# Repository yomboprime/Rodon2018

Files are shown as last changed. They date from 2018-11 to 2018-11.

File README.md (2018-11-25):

# Rodon2018
Open source wheeled robot.

This project will hold schematics, designs and code for a complete robot.

The robot electronics consist of an SBC (Raspberry-like board) and a Arduino/ESP/STM32-like board.

The main goal of the project is to create software for a wheeled robot suited for a diversity of common controller boards and hardware, i.e. Raspberry-like boards, microcontroller boards, and "Arduino modules". The particular hardware used in the project may differ from yours.

The libre tools used are: Kicad for the electronics, Freecad and Blender for the 3D designs, Inkscape for 2D artwork, and your favourite manner of editing code.

## Documentation

Please read the [project documentation](doc/1_DocumentationMain.md)

## Project phases history

- ✔️ Design MicrocontrollerBoard: Kicad design for the microcontroller board (Atmega1284P-PU)
- ➡️ Ordering and waiting for PCB arrival.
- Test MicrocontrollerBoard with motors.
- Do code a basic software & firmware.
- Keep growing functionality

## Acknowledgements

The small Lidar sensor code is based on the Adafruit VL53L0X Library, which is also MIT Licensed:

### Adafruit VL53L0X Library 

This is a library for the Adafruit VL53L0X time-of-flight breakout:
  * https://www.adafruit.com/products/3317
 
Check out the links above for our tutorials and wiring diagrams. This chip uses I2C to communicate

Adafruit invests time and resources providing this open source code, please support Adafruit and open-source hardware by purchasing products from Adafruit!

Written by Limor Fried/Ladyada for Adafruit Industries.
MIT license, all text above must be included in any redistribution

## License

MIT Licensed, see LICENSE file.

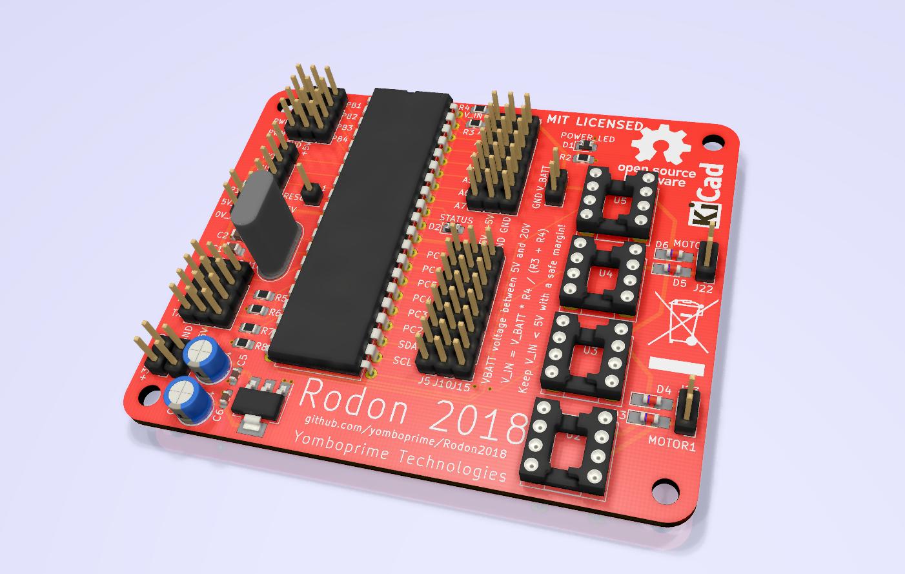
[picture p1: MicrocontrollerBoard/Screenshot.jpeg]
MicrocontrollerBoard


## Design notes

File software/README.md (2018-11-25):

# Software for Rodon2018 robot

- **Neocortex** is the Node.js software that runs on [CPUBoard](../doc/3_CPUBoard.md)
- **Medula_A** is the Arduino software that runs on [MicrocontrollerBoard](../doc/2_MicrocontrollerBoard.md) number 1.
- **Medula_B** is the Arduino software that runs on [MicrocontrollerBoard](../doc/2_MicrocontrollerBoard.md) number 2.

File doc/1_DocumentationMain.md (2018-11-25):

# Rodon2018 Documentation

## Components

The following sections define the different components of the robot.

- Electronics
- Sensors
- Actuators
- Power supply

### Electronics

The robot electronics consist of an SBC (Raspberry-like board) and a Arduino/ESP/STM32-like board. The particular hardware used in this project may differ from yours.

The first one has high level functions, while the second one controls hardware in real time. I will name them this way:

- CPUBoard: A GNU/Linux board (i.e., an SBC) You can use any Raspberry-like board for this.
- MicrocontrollerBoard: a microcontroller one. Any Arduino/ESPxx/STM board will be fine.

The CPUBoard code is cross-platform since it is Node.js based, and the Arduino code should be straightforward to run or port to other microcontrollers.

The CPUBoard will communicate with (and control the)  MicrocontrollerBoard through a serial port.

#### CPUBoard

This board will process high level functions and serve a web based interface.

The CPUBoard should have WiFi, and USB 2.0 support (to use a USB webcam, or alternatively, some other camera supported in Video4Linux). It should also have audio mic/output connectors, but it doesn't need video output. One UART is also needed. The UART can be a USB dongle one. If the UART is integrated, make sure it is the same voltage as the MicrocontrollerBoard one (3.3V or 5V) If it isn't, you should use voltage dividers, see the MicrocontrollerBoard section. 

See [NanoPi-Duo 2 board](3_CPUBoard.md) for more info about the SBC used in the project and how to adapt your own one.

#### MicrocontrollerBoard

The MicrocontrollerBoard controls most of the hardware in real time: it does servos and motors PWM control, read wheel encoders and control other things.

Besides the MicrocontrollerBoard, you will also need an H-Bridge dual motor driver board suited to control the power of the two wheel motors (in voltage and wattage), and another two H-bridges to control the stepper motor of the turret (alternatively a stepper motor driver module can be used for this)

In the project, two [custom MicrocontrollerBoard with integrated dual H-Bridge](2_MicrocontrollerBoard.md) are used. Read the previous link for more info on the board and how to use a generic one.

### Sensors

- [Wheel encoders](4_Sensors.md#wheel-encoders)
- [Turret endstop switch](4_Sensors.md#turret-endstop-switch)
- [Camera](4_Sensors.md#camera)
- [Microphone](4_Sensors.md#microphone)
- [Big lidar sensor](4_Sensors.md#big-lidar-sensor)
- [Small lidar sensor](4_Sensors.md#small-lidar-sensor)

### Actuators

- [Robot platform and motors](5_Actuators.md#robot-platform-and-motors)
- [Camera turret with stepper motor](5_Actuators.md#turret)
- [Arm](5_Actuators.md#arm)
- [Speaker](5_Actuators.md#speaker-and-audio-amplifier)
- [LED light](5_Actuators.md#led-light)

### Power supply

- [LiPo battery](6_PowerSupply.md#lipo-battery)
- [Step-down buck voltage converter](6_PowerSupply.md#step-down-buck-voltage-converter)

## Components interconnections

The following diagram shows the interconnections between the different components or modules.

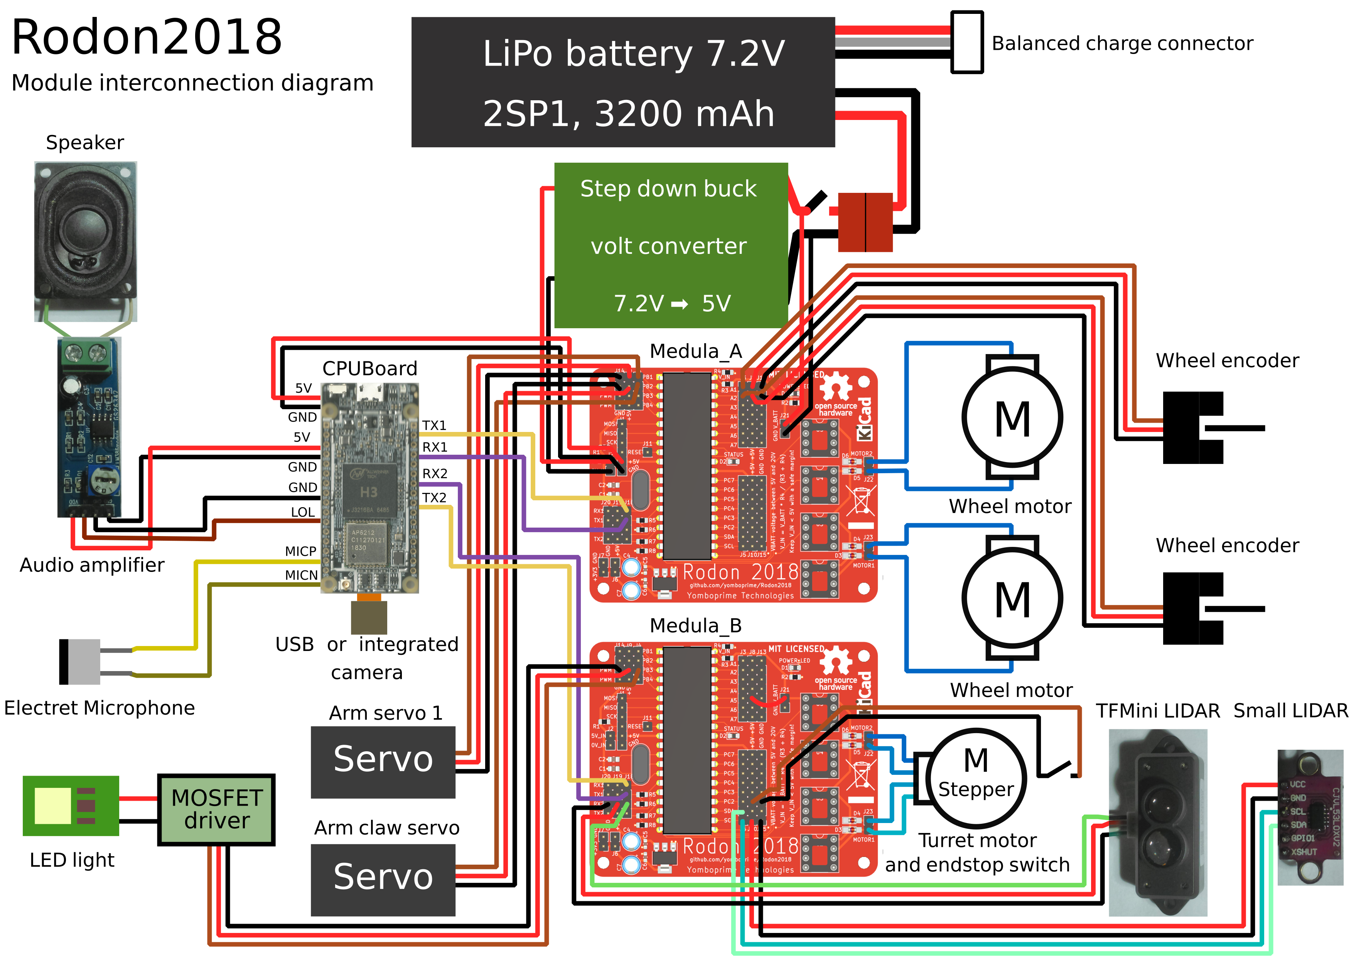
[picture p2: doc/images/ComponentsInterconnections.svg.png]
ComponentsInterconnections


**Legend:**

- LOL: Line Out Left, The left channel audio output pin.
- MICP, MICN: Positive and negative microphone pins.
- TX1, RX1: Transmit and receive pins of UART1
- TX2, RX2: Transmit and receive pins of UART2

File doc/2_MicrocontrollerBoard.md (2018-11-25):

# MicrocontrollerBoard

The MicrocontrollerBoard controls the motors, servos, reads the wheel encoders and activates other low bandwidth stuff. It responds to commands from the [CPUBoard](3_CPUBoard.md).

As with other components of the robot, you can use any Arduino/ESP/STM32 board you have around, the code is compatible. Just keep in mind:
 
- Check the voltage between the MicrocontrollerBoard and the CPUBoard. If both are 3.3V, everything is fine, but if one of them is 5V, you'll have to convert the voltages for the communication lines from 5V to 3V (unless the CPUBoard has also 5V UART, which is unlikely)
- You will need two resistors to form a voltage divider for the battery voltage sensing function.

Both of these points are implemented in the project's custom MicrocontrollerBoard.

As the software library used for the small LIDAR sensor is synchronous, I've decided to use two MicrocontrollerBoard's. This means I have 2x processing time. The reading of the two LIDARs and the turret motor control is done in the second MicrocontrollerBoard. If you use for example an ESP32, which has two cores, you can create two tasks and assign each one the `setup()` and `loop()` of each of the two Arduino sketches.

The software for the MicrocontrollerBoard is called Medula. Since there are two MicrocontrollerBoard's, the Arduino sketches are called **Medula_A** and **Medula_B**. Also, the CPUBoard needs two UARTs to communicate with them. 

**The code for this board is W.I.P.**

## Pins, peripherals, pinout assignment

Check the pinout assignment with your board and change the code accordingly.

The needed pins/peripherals on the MicrocontrollerBoard are:

- 4x PWM output pins for the wheel motors.
- 2x digital input pins for the wheel encoders.
- 4x output pins for the turret stepper motor.
- 1x digital input pin for the turret endstop switch.
- 1x analog input with two resistors forming a voltage divider, to sense the battery voltage.
- 1x UART for communications with the CPUBoard
- 1x UART to read the TFMini LIDAR.
- 1x I2C to read the small LIDAR sensor.
- A way for programming it, either ICSP or another UART via bootloader.

## Project board
 
The board used and designed for this project uses an Atmel ATMEGA1284P-PU microcontroller. It is designed with a mix of THT and SMD components I had laying around. Its features are:

- Supply voltage is 5V
- 16 MHz crystal is used.
- Dual Full H-Bridge implemented with four TC4422 (2A per motor)
- Separate motor battery voltage from 5V to 20V
- Exposes 22 pins with neighbour 5V and GND (7 of the pins are analog inputs, 2 have hardware PWM, 2x UART, 1x I2C)
- Voltage conversion resistors for 2xUART, and A0 (analog input 0, to sense battery voltage)
- Can be programmed via bootloader (UART) or ICSP (SPI)
- 3V3 voltage regulator to power other modules.
- Power indication LED
- Status (general purpose) LED on PB0

The Kicad design of this board is located [here](../MicrocontrollerBoard/kicad_project/).

Two of this boards are used, distributing the connected peripherals as follows:

### MicrocontrollerBoard: Medula_A

- The two H-bridges control the wheel motors.
- The two wheel encoders are connected to pins A1 and A2.
- 7.2V battery voltage is measured at V_IN (A0)
- UART1 (Serial) is connected to CPUBoard. UART2 is not used.
- 5V voltage from the step-down converter is connected to this board and distributed from here to CPUBoard, Medula_B and all other modules.

### MicrocontrollerBoard: Medula_B

- The two H-bridges control the turret stepper motor.
- The turret endstop switch is connected to PC2 pin.
- The TFMini LIDAR is connected to UART2 (Serial1) Only the TX pin from the LIDAR is used.
- The small LIDAR is connected via I2C (pins SCL and SDA)
- UART1 (Serial) is connected to CPUBoard.

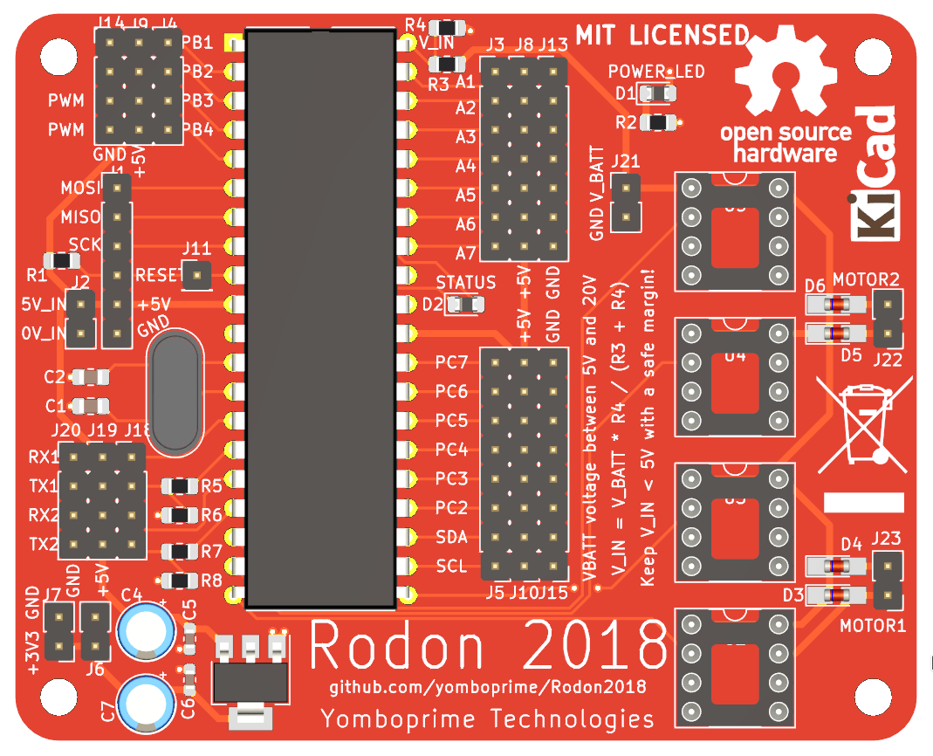
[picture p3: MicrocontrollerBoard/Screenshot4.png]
MicrocontrollerBoard


MicrocontrollerBoard

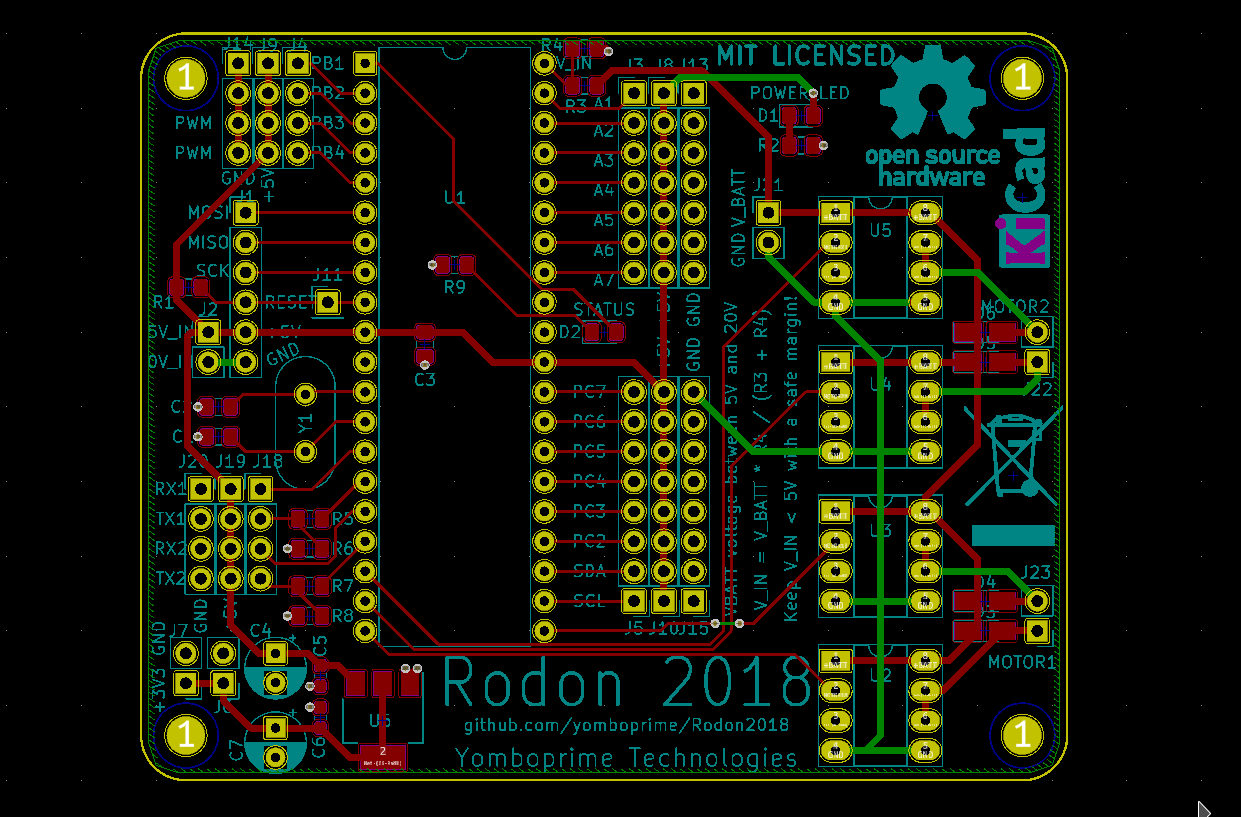
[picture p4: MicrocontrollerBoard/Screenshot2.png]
MicrocontrollerBoard2


### Voltage dividers

A voltage divider is used to convert a voltage to a lower one and is formed by two resistors, let's say Ra and Rb. These two resistors are connected in series. Ra is connected in one end to the higher voltage, the point between Ra and Rb is connected to the lower voltage output, and the other Rb end is connected to ground. Then, `Vlow = Vhigh * Rb / ( Ra + Rb)`.

#### UART voltage dividers

To allow the conversion of 5V to 3V3 on the communication pins that are outputs (TX) connected to the [CPUBoard](3_CPUBoard.md), consult the values for each resistor pair:

Output pin|Ra|Rb
----------|--|--
TX1|R5 = 1K|R6 = 2K
TX2|R7 = 1K|R8 = 2K
MISO|R10 = 1K|R11 = 2K

Note that only output pins need conversion. Driving a 5V input from a 3V3 output is safe.

Also, TX2 voltage divider may not be needed.

#### Battery sense voltage divider

The battery voltage, which can be greater than 5V, is read through an analog input pin which can tolerate a maximum of 5V. To do this, a voltage divider is used with V_BATT as input and V_IN as output, using R3 and R4, with values near to 1K.

To calculate the values for R3 and R4:

`V_IN = V_BATT * R4 / (R3 + R4)`

If we want to be able to measure 2S and 3S batteries, say a 15V maximum is a safe top level. Then,

`5V = 15V * R4 / (R3 + R4)`

`1/3 = R4 / (R3 + R4)`

`(R3 + R4) / 3 = R4`

`((R3 / R4) + 1) / 3 = 1`

`R3 / R4 = 2`

`R3 = 2 * R4`

If we choose R4 = 1K, then R3 must be 2K. We choose the standard value 2K2, and then calculate again the max voltage we'll get at V_IN:

`V_IN = 15V * 1K / (1K + 2K2)`

`V_IN = 4.6875V`

So we can get again the theoretical maximum measurable voltage based on these resistors values:

`V_BATT = 15V * 5v / 4.6875V = 16V`

Which is exactly 16V.

So we can use the 10 bit ADC from the ATMEGA microcontroller to measure in steps of 16V/1024, or 15.625mV.

To calibrate with the real resistors values, the V_BATT, R3_RESISTOR and R4_RESISTOR values can be changed in the code. (W.I.P.)

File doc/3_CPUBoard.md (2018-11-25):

# CPUBoard

CPUBoard is the board used as the main robot CPU. As with other components of the robot, you can use any Raspberry-like board you've got around, the code is compatible. The robot server software that runs in CPUBoard is called Neocortex and is written in js. It runs in Node.js, which is a multi-platform runtime for the js language. When using your CPUBoard just keep in mind:
 
- Check the voltage between the CPUBoard and the MicrocontrollerBoard. If both are 3.3V, everything is fine, but if one of them is 5V, you'll have to convert the voltages for the communication lines from 5V to 3V. This is done in the [custom MicrocontrollerBoard](2_MicrocontrollerBoard.md)

## Features of CPUBoard

The needed features on the CPUBoard are:

- Compatible GNU/Linux operating system.
- WiFi
- 2x UART to communicate with the two MicrocontrollerBoards (or only one if you use only one MicrocontrollerBoard, like an ESP32)
- A video camera compatible with Video4Linux.
- Analogue audio output (mono, or stereo if you want)
- Analogue microphone input.

## Project board

The CPUBoard used in this project is a [FriendlyArm NanoPi-Duo 2 SBC](http://wiki.friendlyarm.com/wiki/index.php/NanoPi_Duo2), which is a SBC in very small factor with only pin headers broken out, a OV5640 video camera connector, microUSB and microSD.

The pins corresponding to the SPI port are used here as the alternate function (a second UART) So SCK corresponds to RX2, and CS to TX2.

## The software: Neocortex

**The code for this board is W.I.P. and is not completed yet.**

### Prerequisites instalation

- Node.js is required. Read [Node.js docs](https://nodejs.org/) on how to install for your OS.

### Instalation

W.I.P

- Clone [Rodon2018 repository](https://github.com/yomboprime/Rodon2018.git) into the CPUBoard file system (`Rodon2018/` from now on)
- Install Node.js library dependecies by issuing these commands:
  - `cd Rodon2018/software/Neocortex/`
  - `npm install`

### WiFi configuration

Please refer to your OS documentation on how to set up a WiFi network. You can either:

- Use a common WiFi network accessible by CPUBoard and the client system/s, or
- Configure CPUBoard to create an adhoc WiFi network, accessible by the client/s.

It is recommended to set a static IP so you won't have to find CPUBoard in the network each time.

### Running Neocortex in CPUBoard

#### Executing to test it

To simply do a run test of the software, do just:

- `cd Rodon2018/software/Neocortex/`
- `npm start`

Press (ctrl-c) to exit at any time.

#### Run at system startup

To execute Neocortex at system startup automatically, usually adding these lines at the end of the `/etc.rc.local` file will suffice:

- `cd /absolute_path_to_Rodon2018/software/Neocortex/`
- `npm start || exit 1`
- `exit 0`

In this configuration, the system will have to be shutdown by the client web interface or from a ssh terminal.

#### Running the web interface in a client

Any browser-capable device can be a client. Just:

- Connect to the same network the CPUBoard is connected to.
- Navigate with a modern browser to `http://<ip>:<port>/public`

Where:

- `<ip>` is the static IP address of CPUBoard in the network.
- `<port>` is the application TCP port as defined in the Neocortex configuration file (TODO link file doc).

Example: `http://192.168.1.189:8090/public`

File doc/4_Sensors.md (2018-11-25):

# Sensors

## Wheel encoders

Simple on/off encoders are used, to provide speed/relative movement between readings for each wheel. You can set the number of marks per revolution in the code. The left and right wheel encoders are attached to two pins on the [MicrocontrollerBoard](2_MicrocontrollerBoard.md)

## Turret endstop switch

A common switch of any type can be used. It must be normally-open type.

## Camera

A USB webcam or integrated camera which can support Video4Linux can be used, attached to the [CPUBoard](3_CPUBoard.md) First I was going to use this cheap VGA USB camera, but then upgraded to Nanopi-Duo 2 for the CPUBoard which has integrated 1080p@30FPS camera sensor.

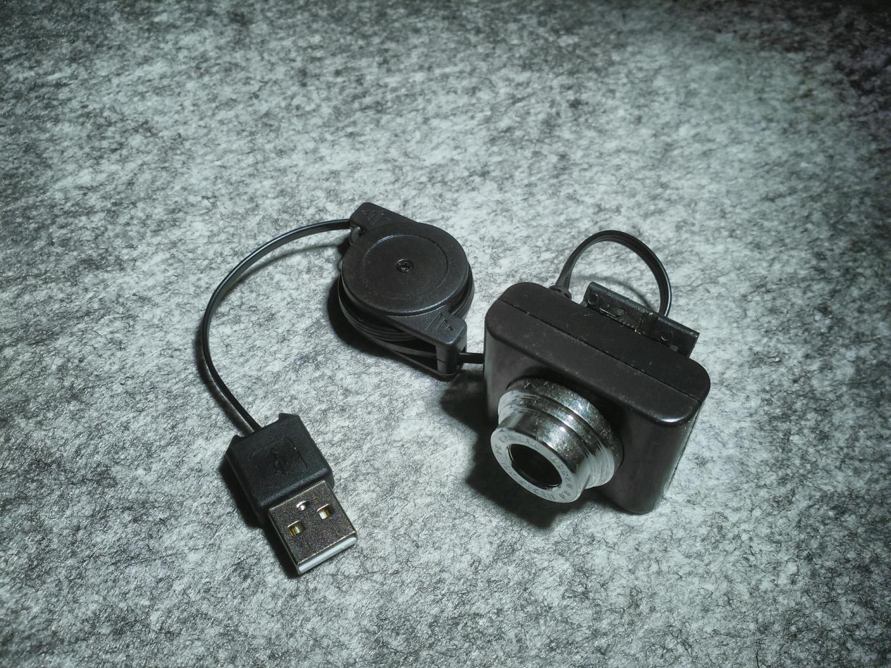
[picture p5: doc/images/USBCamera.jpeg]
USBCamera


## Microphone

Any microphone that can be connected to the MIC input of your [CPUBoard](3_CPUBoard.md) will serve. A simple and inexpensive electret microphone is used in the project, connected directly to the MICP and MICN (positive and negative) inputs in the CPUBoard. Keep in mind the polarity, the negative pin in the electret is the one connected to the chassis with pcb tracks in the back, as shown in the following photo.

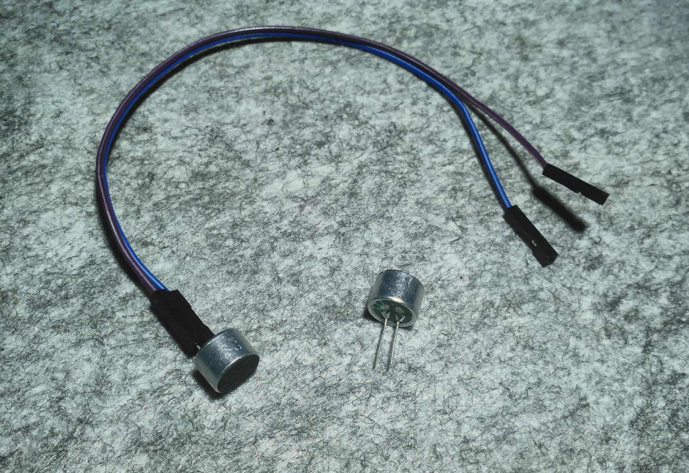
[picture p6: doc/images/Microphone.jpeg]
Microphone


## Big LIDAR Sensor

The TF-Mini LIDAR sensor is a 30 to 2000 cm range LASER distance sensor with 1 cm precision and UART interface. Only TX line (reading from the sensor) is needed, attached to the [MicrocontrollerBoard](2_MicrocontrollerBoard.md) Medula_B

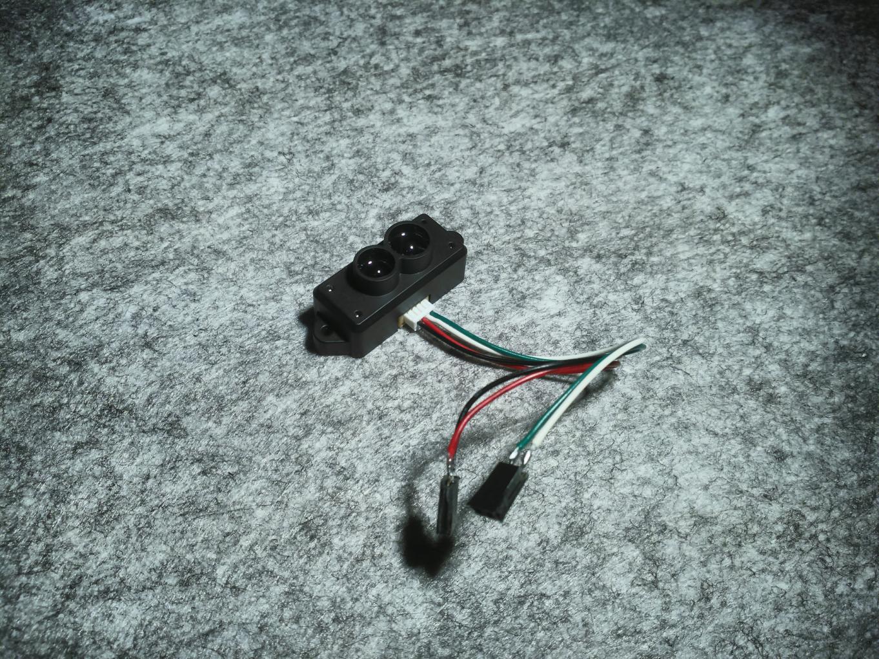
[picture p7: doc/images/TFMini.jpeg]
TFMini


## Small LIDAR Sensor

The V53L0X LIDAR sensor is used in conjunction with the TF-Mini to increase its short range capabilities. This is a 5 to 120 cm range LIDAR sensor with 1 mm precision. I has I2C interface, connected to the [MicrocontrollerBoard](2_MicrocontrollerBoard.md) Medula_B

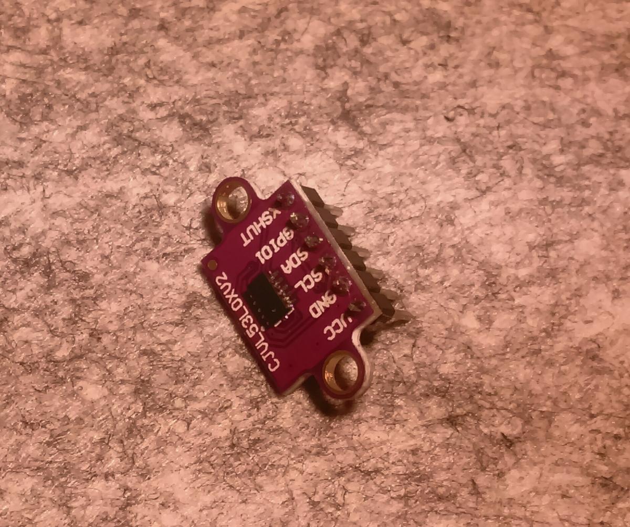
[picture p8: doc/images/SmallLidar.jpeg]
SmallLidar


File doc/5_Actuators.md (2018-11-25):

# Actuators

## Robot platform and motors

Any robot base with motors and wheel encoders can be used. In the project, an old robot platform is used (which parts were included in magazines from the old company EagleMoss Publications Ltd.) Wheel encoders obtained from an old matrix printer were added (they have 50 marks per revolution). Also was added to the platform a stronger free rotation third wheel. A black electronics box was also installed. 3D printed parts will be added for the turret and arm.

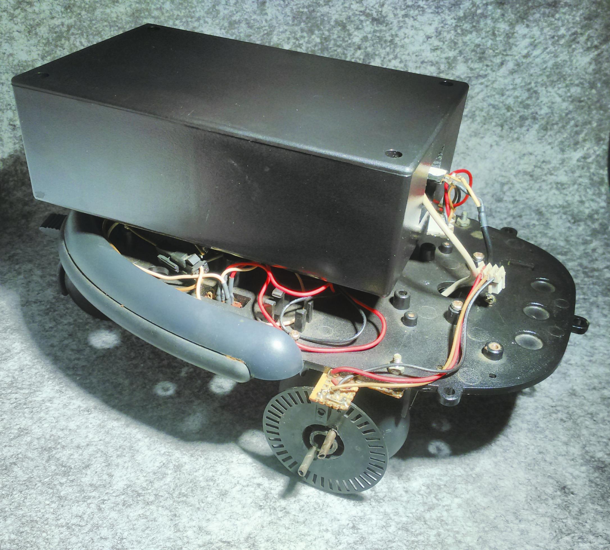
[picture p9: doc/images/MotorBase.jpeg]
MotorBase


W.I.P.

## Turret

A custom 3D printed turret which holds the [CPUBoard](3_CPUBoard.md) and its integrated camera (and also the two LIDARs) will be mounted. It will rotate with a small 5V stepper motor. The turret will only rotate horizontally.

W.I.P.

## Arm

A custom 3D printed arm which can lift soda cans will be mounted. It will have a medium size servo for the arm and a miniservo for the clamp.

W.I.P.

## Speaker and audio amplifier

A speaker with an audio amplifier module at 5V will be used to reproduce sounds from the [CPUBoard](3_CPUBoard.md). Just mono sound is OK.

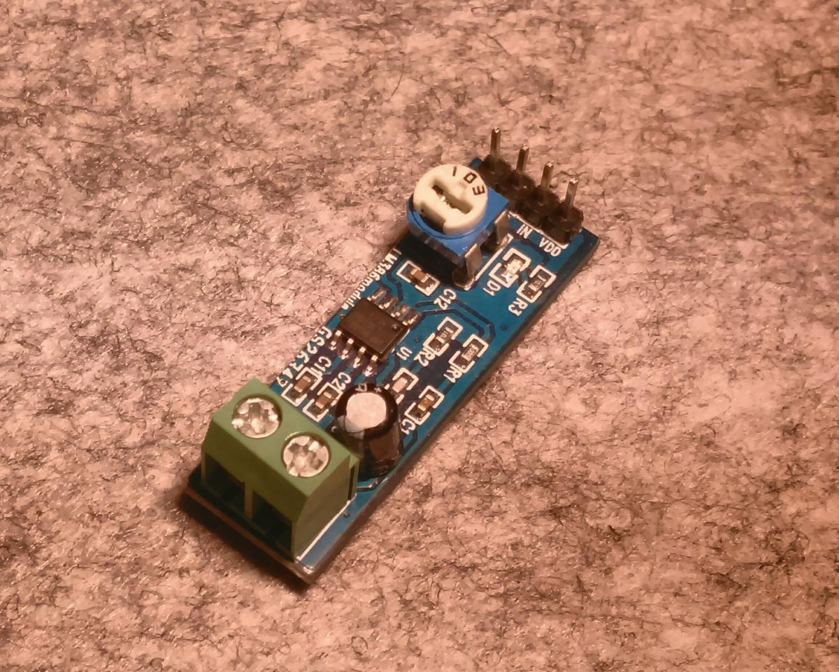
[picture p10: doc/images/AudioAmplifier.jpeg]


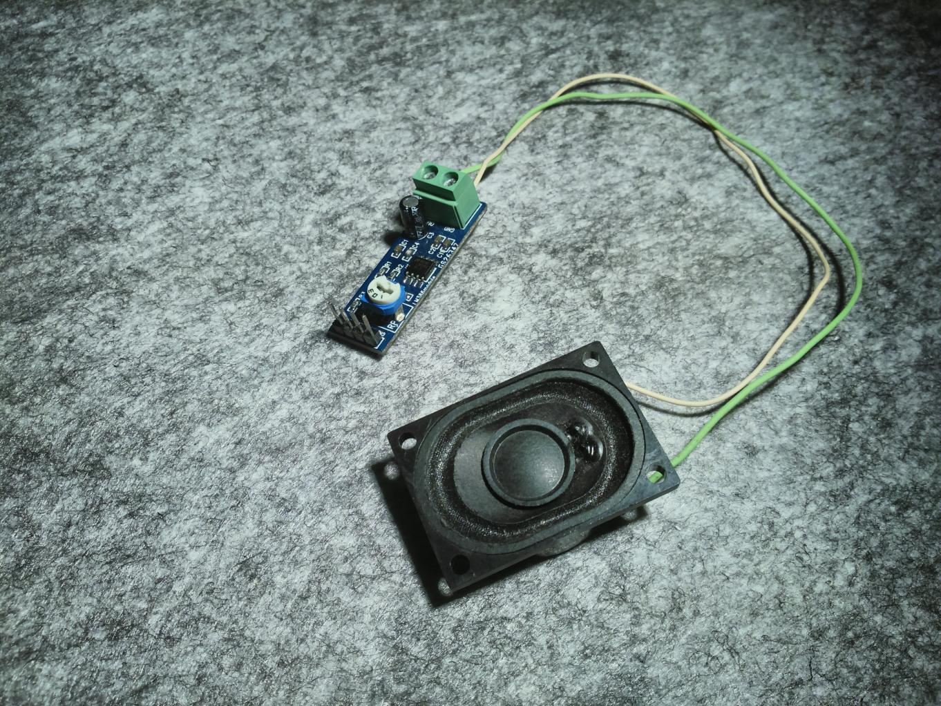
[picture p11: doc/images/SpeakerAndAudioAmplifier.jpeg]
SpeakerAndAudioAmplifier


## LED light

A LED light is used for illumination. It can be any power LED with its current limiting resistor. It is controlled with a MOSFET driver at 5V.

W.I.P.

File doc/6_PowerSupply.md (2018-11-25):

# Power supply

The robot can be powered with Li-Po or Li-ion batteries. Best is two or three cells (2S/3S batteries)

The batteries will have to be charged either by extracting them or providing a charging circuit.

In the project, a *deans* connector is used to unconnect from the robot and connect to the charger externally. During development, a LiPo battery tester is used, connected to the balanced charge connector.

## LiPo battery

In the project, a 2S Li-Po battery with 3300 mAh charge is used. During periods of non use it will be extracted and kept safe.

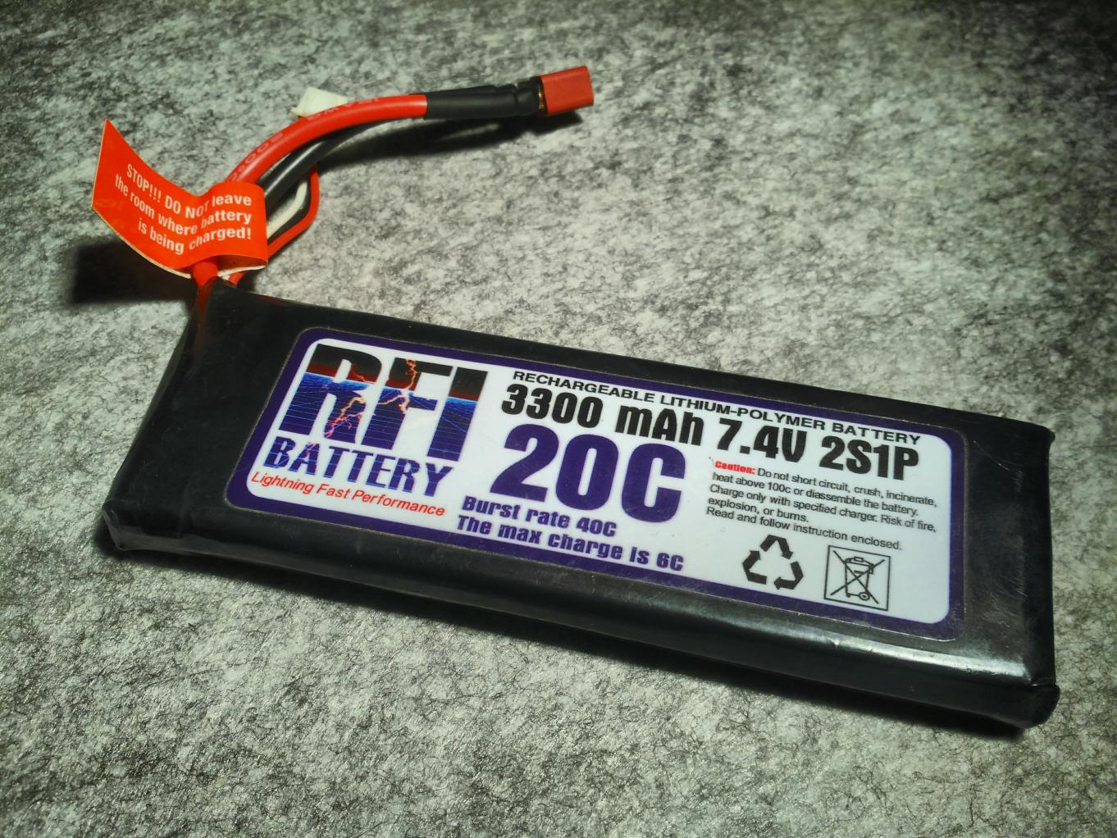
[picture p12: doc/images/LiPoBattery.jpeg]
LiPoBattery


## Step-down buck voltage converter

To provide 5V for the [CPUBoard](3_CPUBoard.md) and the [MicrocontrollerBoard](2_MicrocontrollerBoard.md), a step-down buck converter will be used. The battery voltage will be applied to its input, and it will supply 5V @ 4A to both boards. These step down modules are adjusted without load before operation, with its potentiometers.

You can decide in your robot at what voltage you want to run the servos and the motors. Servos can be used with 2S batteries (up to about 7.4V), but 3S (11V or more) is too high. Check also your motors maximum voltage.

In the project, the 2S battery is connected to the battery connector in the [MicrocontrollerBoard](2_MicrocontrollerBoard.md), so the battery powers the motors directly. On the other hand, the servos and the turret motor are powered with 5V.

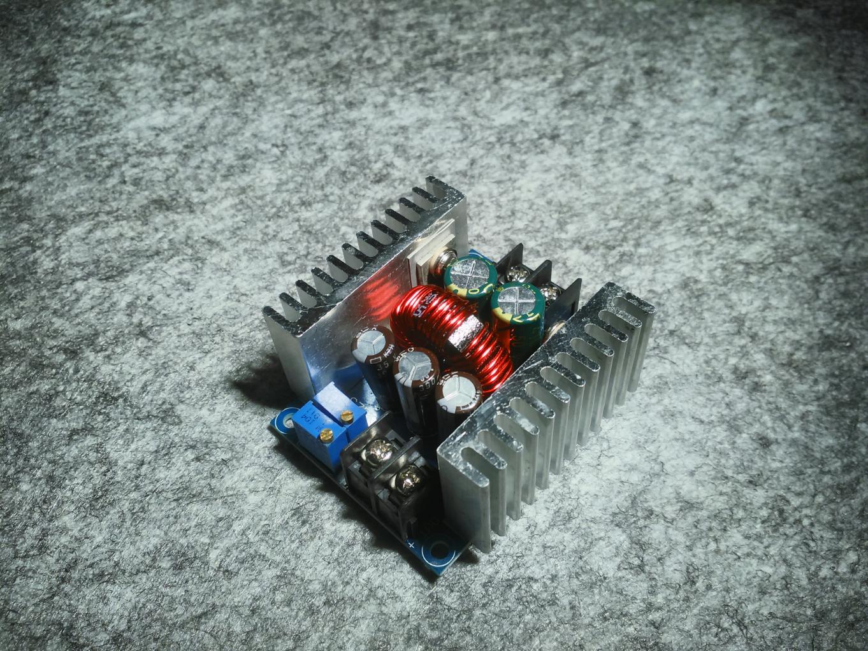
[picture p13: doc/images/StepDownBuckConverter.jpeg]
StepDownBuckConverter


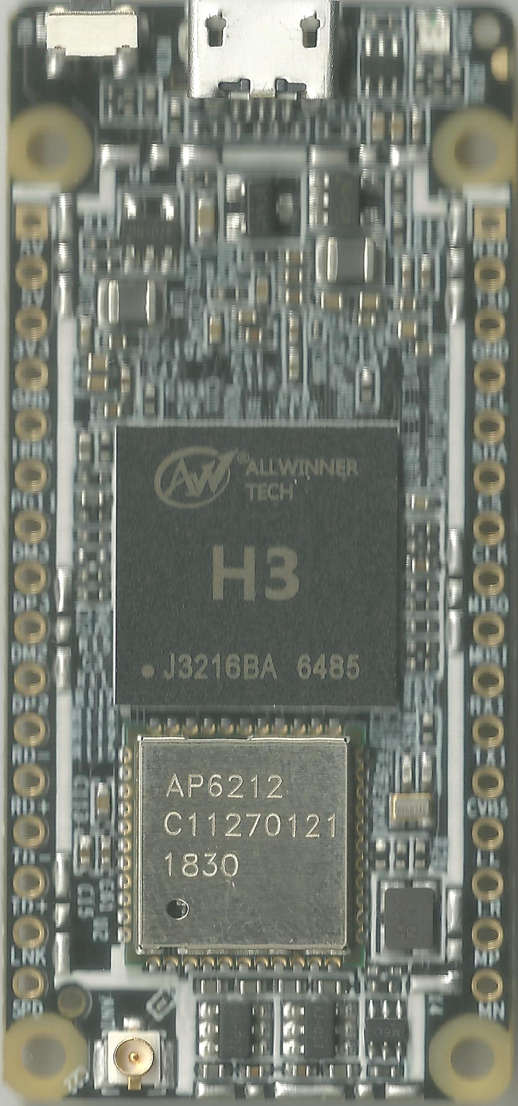
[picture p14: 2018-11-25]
doc/images/Nanopi_Duo_2.jpeg

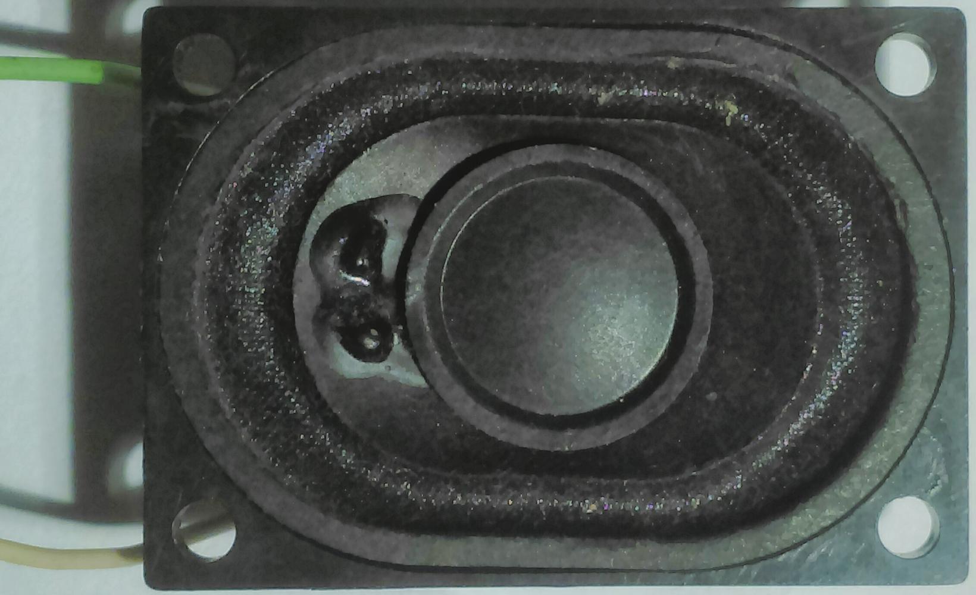
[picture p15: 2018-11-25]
doc/images/Speaker_Plant.jpeg

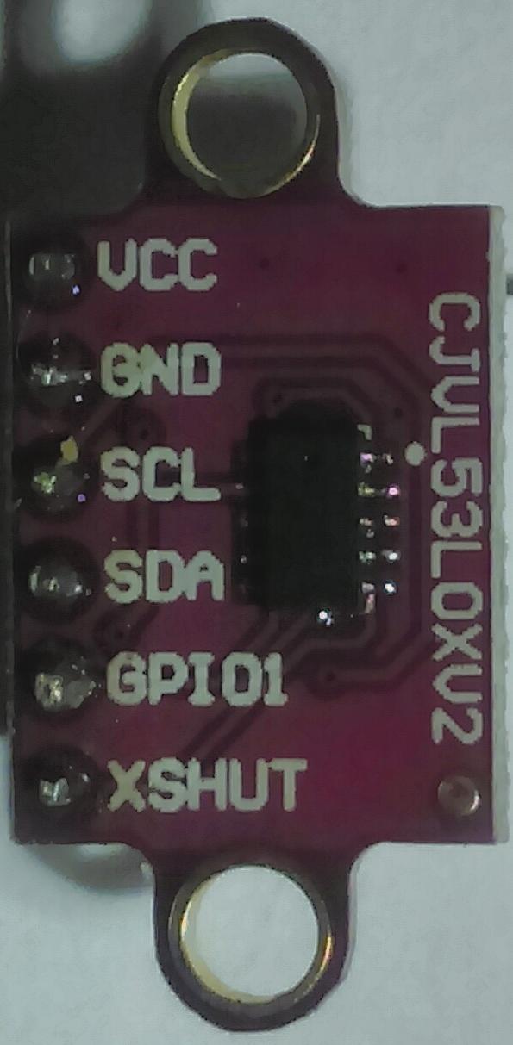
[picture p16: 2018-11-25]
doc/images/SmallLidar_Plant.jpeg

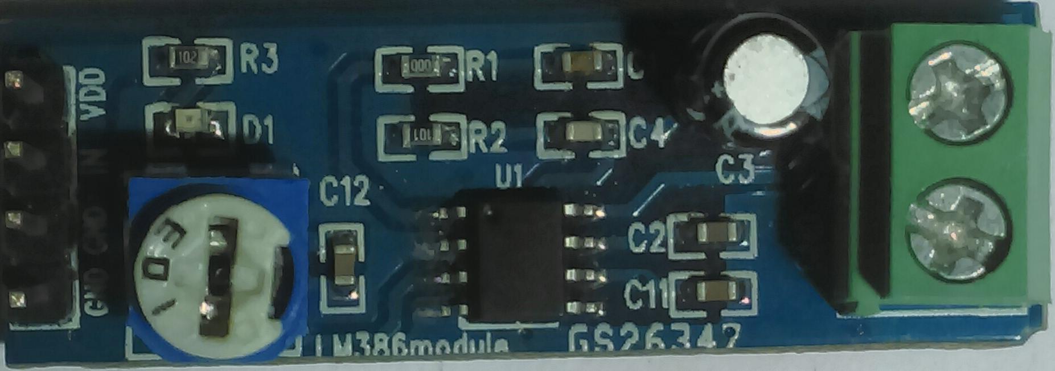
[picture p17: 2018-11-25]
doc/images/AudioAmplifier_Plant.jpeg

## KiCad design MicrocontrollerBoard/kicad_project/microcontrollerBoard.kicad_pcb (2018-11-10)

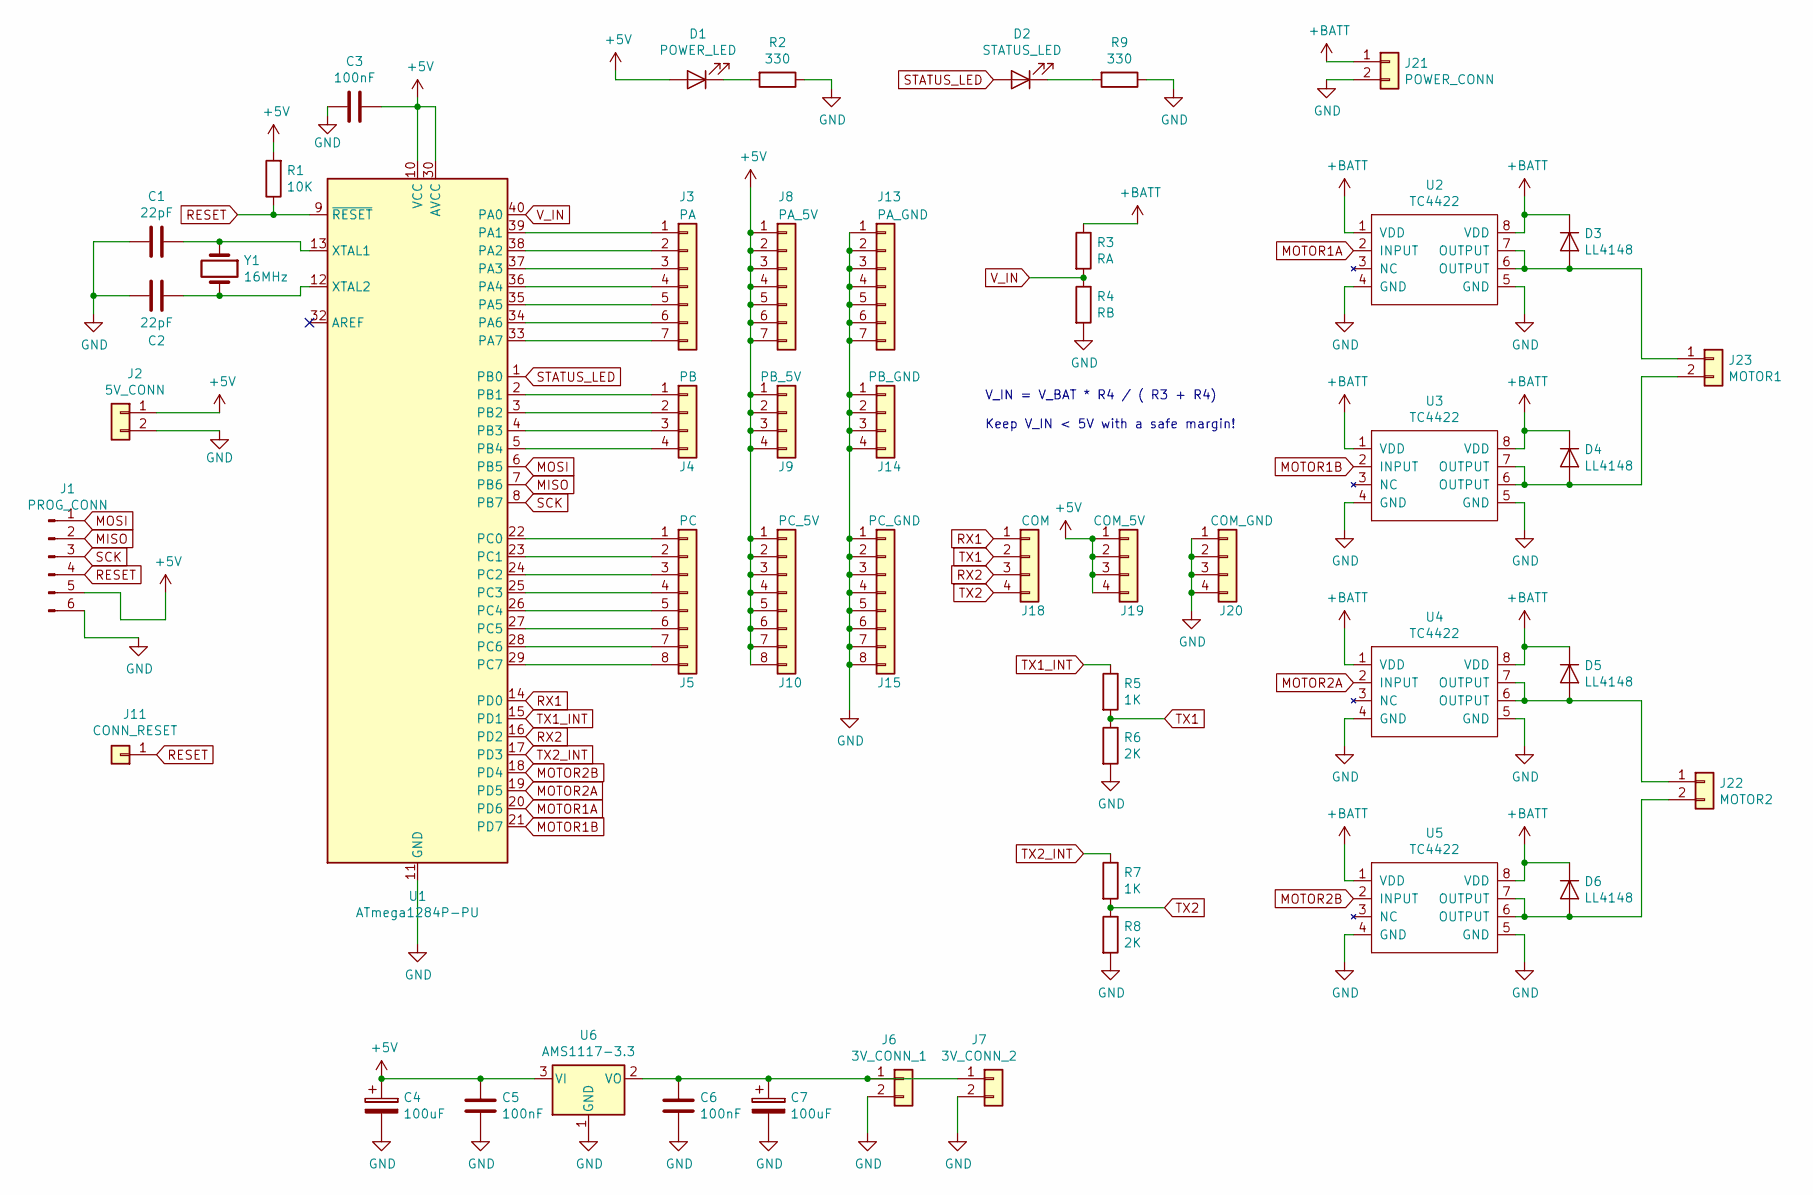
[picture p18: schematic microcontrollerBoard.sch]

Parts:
C1, C2: 22pF; C_0805_2012Metric_Pad1.15x1.40mm_HandSolder
C3: 100nF; C_0805_2012Metric_Pad1.15x1.40mm_HandSolder
C4, C7: 100uF; CP_Radial_D5.0mm_P2.50mm
C5, C6: 100nF; C_0603_1608Metric_Pad1.05x0.95mm_HandSolder
D1: POWER_LED; D_0805_2012Metric_Pad1.15x1.40mm_HandSolder
D2: STATUS_LED; D_0805_2012Metric_Pad1.15x1.40mm_HandSolder
D3, D4, D5, D6: LL4148; D_SOD-110
J1: PROG_CONN; PinHeader_1x06_P2.54mm_Vertical
J2: 5V_CONN; PinHeader_1x02_P2.54mm_Vertical
J3: PA; PinHeader_1x07_P2.54mm_Vertical
J4: PB; PinHeader_1x04_P2.54mm_Vertical
J5: PC; PinHeader_1x08_P2.54mm_Vertical
J6: 3V_CONN_1; PinHeader_1x02_P2.54mm_Vertical
J7: 3V_CONN_2; PinHeader_1x02_P2.54mm_Vertical
J8: PA_5V; PinHeader_1x07_P2.54mm_Vertical
J9: PB_5V; PinHeader_1x04_P2.54mm_Vertical
J10: PC_5V; PinHeader_1x08_P2.54mm_Vertical
J11: CONN_RESET; PinHeader_1x01_P2.54mm_Vertical
J13: PA_GND; PinHeader_1x07_P2.54mm_Vertical
J14: PB_GND; PinHeader_1x04_P2.54mm_Vertical
J15: PC_GND; PinHeader_1x08_P2.54mm_Vertical
J18: COM; PinHeader_1x04_P2.54mm_Vertical
J19: COM_5V; PinHeader_1x04_P2.54mm_Vertical
J20: COM_GND; PinHeader_1x04_P2.54mm_Vertical
J21: POWER_CONN; PinHeader_1x02_P2.54mm_Vertical
J22: MOTOR2; PinHeader_1x02_P2.54mm_Vertical
J23: MOTOR1; PinHeader_1x02_P2.54mm_Vertical
R1: 10K; R_0805_2012Metric_Pad1.15x1.40mm_HandSolder
R2, R9: 330; R_0805_2012Metric_Pad1.15x1.40mm_HandSolder
R3: RA; R_0805_2012Metric_Pad1.15x1.40mm_HandSolder
R4: RB; R_0805_2012Metric_Pad1.15x1.40mm_HandSolder
R5, R7: 1K; R_0805_2012Metric_Pad1.15x1.40mm_HandSolder
R6, R8: 2K; R_0805_2012Metric_Pad1.15x1.40mm_HandSolder
U1: ATmega1284P-PU; DIP-40_W15.24mm
U2, U3, U4, U5: TC4422; DIP-8_W7.62mm_Socket_LongPads
U6: AMS1117-3.3; SOT-223-3_TabPin2
Y1: 16MHz; Crystal_HC49-U_Vertical

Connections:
+5V: C3.1, C4.1, C5.1, D1.2 (A), J1.5, J2.1, J8.1, J8.2, J8.3, J8.4, J8.5, J8.6, J8.7, J9.1, J9.2, J9.3, J9.4, J10.1, J10.2, J10.3, J10.4, J10.5, J10.6, J10.7, J10.8, J19.1, J19.2, J19.3, J19.4, R1.2, U1.10 (VCC), U1.30 (AVCC), U6.3 (VI)
+BATT: D3.1 (K), D4.1 (K), D5.1 (K), D6.1 (K), J21.1, R3.1, U2.1 (VDD), U2.8 (VDD), U3.1 (VDD), U3.8 (VDD), U4.1 (VDD), U4.8 (VDD), U5.1 (VDD), U5.8 (VDD)
GND: C1.2, C2.2, C3.2, C4.2, C5.2, C6.2, C7.2, J1.6, J2.2, J6.2, J7.2, J13.1, J13.2, J13.3, J13.4, J13.5, J13.6, J13.7, J14.1, J14.2, J14.3, J14.4, J15.1, J15.2, J15.3, J15.4, J15.5, J15.6, J15.7, J15.8, J20.1, J20.2, J20.3, J20.4, J21.2, R2.1, R4.2, R6.2, R8.2, R9.1, U1.11 (GND), U1.31 (GND), U2.4 (GND), U2.5 (GND), U3.4 (GND), U3.5 (GND), U4.4 (GND), U4.5 (GND), U5.4 (GND), U5.5 (GND), U6.1 (GND)
MISO: J1.2, U1.7 (PB6)
MOSI: J1.1, U1.6 (PB5)
MOTOR1A: U1.20 (PD6), U2.2 (INPUT)
MOTOR1B: U1.21 (PD7), U3.2 (INPUT)
MOTOR2A: U1.19 (PD5), U4.2 (INPUT)
MOTOR2B: U1.18 (PD4), U5.2 (INPUT)
unnamed: C1.1, U1.13 (XTAL1), Y1.1
unnamed: C2.1, U1.12 (XTAL2), Y1.2
unnamed: C6.1, C7.1, J6.1, J7.1, U6.2 (VO)
unnamed: D1.1 (K), R2.2
unnamed: D2.1 (K), R9.2
unnamed: D3.2 (A), J23.1, U2.6 (OUTPUT), U2.7 (OUTPUT)
unnamed: D4.2 (A), J23.2, U3.6 (OUTPUT), U3.7 (OUTPUT)
unnamed: D5.2 (A), J22.1, U4.6 (OUTPUT), U4.7 (OUTPUT)
unnamed: D6.2 (A), J22.2, U5.6 (OUTPUT), U5.7 (OUTPUT)
unnamed: J3.1, U1.39 (PA1)
unnamed: J3.2, U1.38 (PA2)
unnamed: J3.3, U1.37 (PA3)
unnamed: J3.4, U1.36 (PA4)
unnamed: J3.5, U1.35 (PA5)
unnamed: J3.6, U1.34 (PA6)
unnamed: J3.7, U1.33 (PA7)
unnamed: J4.1, U1.2 (PB1)
unnamed: J4.2, U1.3 (PB2)
unnamed: J4.3, U1.4 (PB3)
unnamed: J4.4, U1.5 (PB4)
unnamed: J5.1, U1.22 (PC0)
unnamed: J5.2, U1.23 (PC1)
unnamed: J5.3, U1.24 (PC2)
unnamed: J5.4, U1.25 (PC3)
unnamed: J5.5, U1.26 (PC4)
unnamed: J5.6, U1.27 (PC5)
unnamed: J5.7, U1.28 (PC6)
unnamed: J5.8, U1.29 (PC7)
RESET: J1.4, J11.1, R1.1, U1.9 (~RESET)
RX1: J18.1, U1.14 (PD0)
RX2: J18.3, U1.16 (PD2)
SCK: J1.3, U1.8 (PB7)
STATUS_LED: D2.2 (A), U1.1 (PB0)
TX1: J18.2, R5.2, R6.1
TX1_INT: R5.1, U1.15 (PD1)
TX2: J18.4, R7.2, R8.1
TX2_INT: R7.1, U1.17 (PD3)
V_IN: R3.2, R4.1, U1.40 (PA0)

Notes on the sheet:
V_IN = V_BAT * R4 / ( R3 + R4) Keep V_IN < 5V with a safe margin!

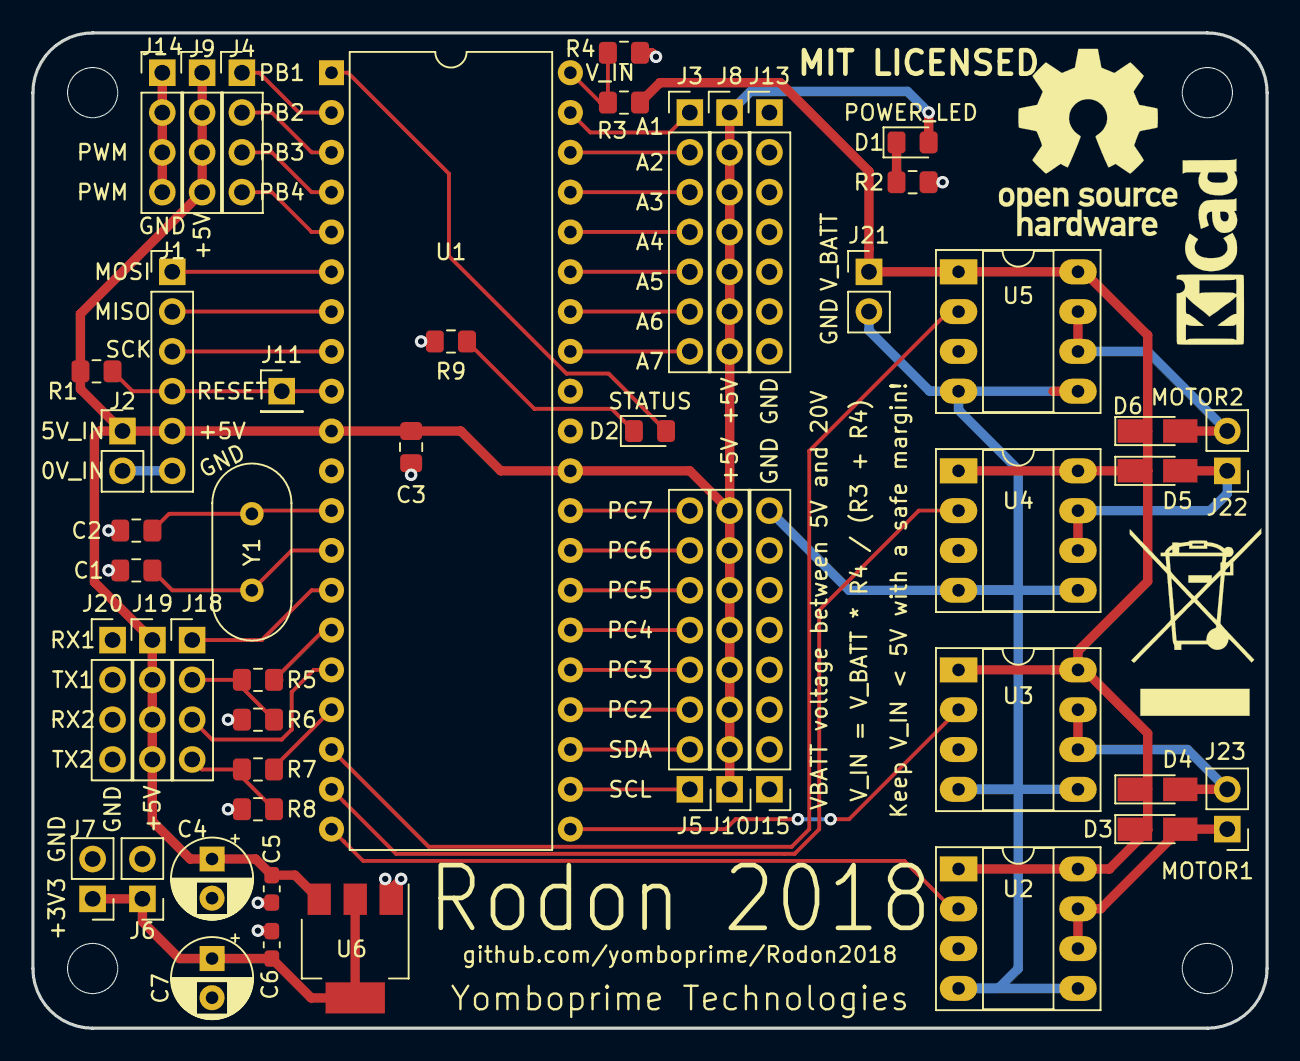
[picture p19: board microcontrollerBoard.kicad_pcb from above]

Board: 2 copper layers, 78.7 x 63.5 mm, 49 parts (0 on the bottom side), 47 nets.

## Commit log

2018-10-18 Microcontroller kicad board design.
    [puenteH-B.Cu.gbl, puenteH-B.Mask.gbs, puenteH-B.SilkS.gbo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]
2018-10-22 Changed TC4422 footprints to non socket so the 3D model has the chips.
    [puenteH-B.Cu.gbl, puenteH-B.Mask.gbs, puenteH-B.SilkS.gbo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]
2018-11-06 Microcontroller bord: Fixed PWM lines not going to uc's PWM pins. Added 3V3 regulator.
    [puenteH-B.Cu.gbl, puenteH-B.Mask.gbs, puenteH-B.SilkS.gbo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]
2018-11-06 Microcontroller board: Some minor fixes.
    [puenteH-B.Cu.gbl, puenteH-B.Mask.gbs, puenteH-B.SilkS.gbo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]
2018-11-06 Microcontroller board: Updated gerbers.
    [puenteH-B.Cu.gbl, puenteH-B.Mask.gbs, puenteH-B.SilkS.gbo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]
2018-11-06 uC board: Renamed board project/directory
    [microcontrollerBoard-B.Cu.gbl, microcontrollerBoard-B.Mask.gbs, microcontrollerBoard-B.SilkS.gbo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]
2018-11-06 uC board: Added resistors to MISO, brought out a RESET pin, minor fixes.
    [microcontrollerBoard-B.Cu.gbl, microcontrollerBoard-B.Mask.gbs, microcontrollerBoard-B.SilkS.gbo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]
2018-11-07 uC board: V_IN is no longer exposed. Better power routing.
    [microcontrollerBoard-B.Cu.gbl, microcontrollerBoard-B.Mask.gbs, microcontrollerBoard-B.SilkS.gbo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]
2018-11-07 uC board: better ground plane connection.
    [microcontrollerBoard-B.Cu.gbl, microcontrollerBoard-B.Mask.gbs, microcontrollerBoard-B.SilkS.gbo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]
2018-11-08 Revised ICSP header, motor diodes.
    [microcontrollerBoard-B.Cu.gbl, microcontrollerBoard-B.Mask.gbs, microcontrollerBoard-B.SilkS.gbo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]
2018-11-08 Update gerbers
    [microcontrollerBoard-B.Cu.gbl, microcontrollerBoard-B.Mask.gbs, microcontrollerBoard-B.SilkS.gbo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]
2018-11-10 uC board: Add motor diodes values (LL4148)
    [microcontrollerBoard.kicad_pcb, microcontrollerBoard.sch]
